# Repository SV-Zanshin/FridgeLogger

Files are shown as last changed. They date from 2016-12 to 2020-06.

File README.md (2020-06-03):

 Wiki (https://github.com/Zanduino/FridgeLogger/wiki)

 # FridgeLogger Program
*Arduino* sketch to log temperature and current consumption data to a microSD card. The statistics collected by this sketch are used to compute various parameters for a refrigerator or freezer. 

## Hardware
Rather than use a prebuilt Arduino, I used an Atmel ATMega 328PU chip with the Arduino bootloader and wired it up on a breadboard with a couple of hardware components, most of which aren't really necessary to the board's function.  I was curious about the Adafruit INA219 breakout board and wired that to the high-side power supply, then ran the power supply through an Adafruit Boost 500 to regulate the power supply, since I'm using rechargeable NiMh batteries and want to keep a nice constant 5V to the breadboard.  A Sparkfun DS1307 breakout board supplies the date and time for the log file. Rather than use a FTDI chip or JTAG programming, I wired in a (removable) Adafruit Bluefruit EZ-Link bluetooth wireless device which allows me to monitor the reading remotely as well as to program the board.
Logging is done using an Adafruit SD-Card breakout board.

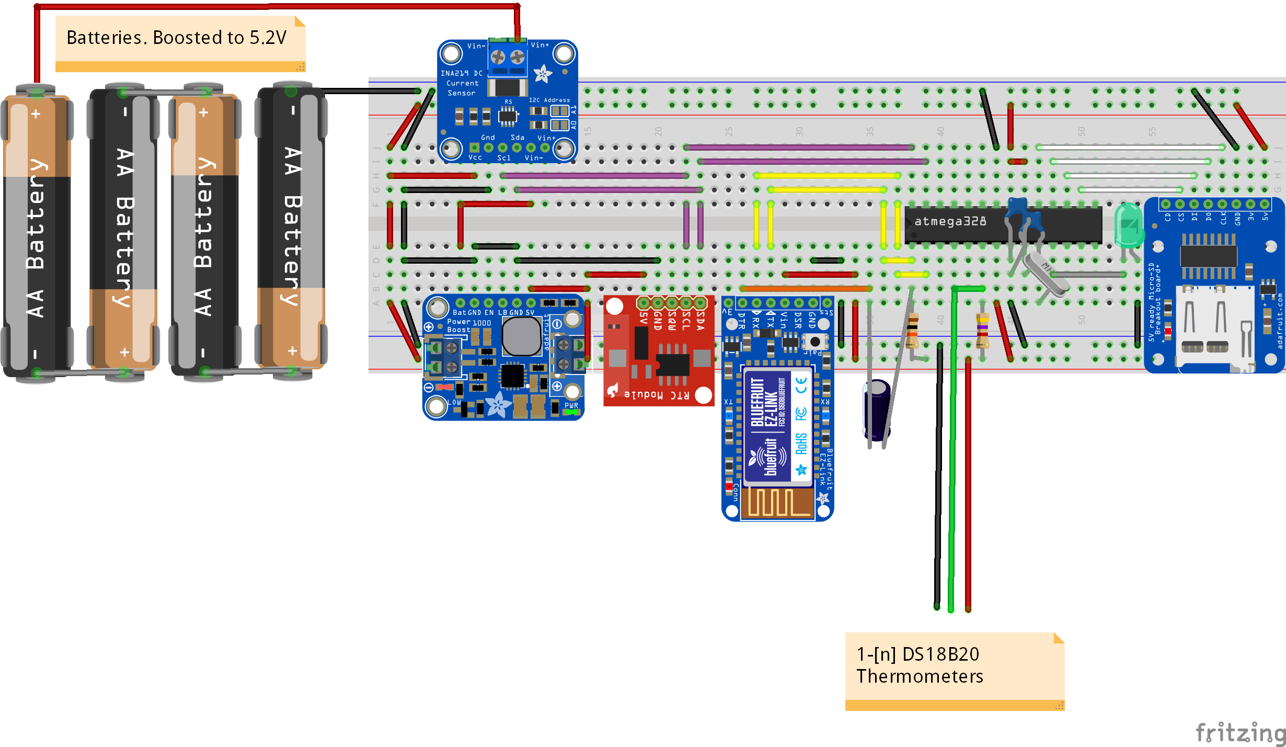
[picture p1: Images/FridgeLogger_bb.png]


## Software
The standard Arduino libraries are used as well as the specific ones for the Sparkfun/Adafruit breakout boards. In addition to these libraries the project makes use of the [DS-Family library](https://github.com/SV-Zanshin/DSFamily) to simplify managing numerous DS-Family type thermometers

## Output Files
The output is written to files on the SD-Card, with a new file started each day. The filename format is "GFYYMMDD.CSV" and the format is a DOS comma-separated variable file. The temperature readings in the file aren't in degrees Celsius, but in the 12-bit internal format used by the DS-Family of devices. Multiply the temperature readings by 0.0625°C to get degrees Celsius.

Zanshin Logo

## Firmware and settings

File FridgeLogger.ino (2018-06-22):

/*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
                            **
** ======= ========== =================== ======================================================================= **
** 1.0.1   2016-12-28 Arnd@SV-Zanshin.Com Added error checking for DS1307 returned date/time                      **
** 1.0.0   2016-12-27 Arnd@SV-Zanshin.Com Implemented                                                             **
** 1.0.0b2 2016-12-25 Arnd@SV-Zanshin.Com Added SD-Card                                                           **
** 1.0.0b1 2016-12-25 Arnd@SV-Zanshin.Com Initial coding.                                                         **
**                                                                                                                **
*******************************************************************************************************************/
#include <Adafruit_INA219.h>                                                  // INA219 Volts and Amps data       //
#include <RTClib.h>                                                           // DS1307 Real-Time-Clock commands  //
#include <SD.h>                                                               // SD-Card input and output         //
#include <avr/sleep.h>                                                        // Sleep mode Library               //
#include <DSFamily.h>                                                         // DS Thermometers calls and methods//
/*******************************************************************************************************************
** Declare program Constants                                                                                      **
*******************************************************************************************************************/
const uint8_t  GREEN_LED_PIN         =      5;                                // Green LED (nonstandard location) //
const uint8_t  CS_PIN                =     10;                                // Chip-Select pin for SD-Card      //
const uint8_t  INA219_I2C_ADDRESS    =   0x40;                                // I2C address = 1000000 (A0+A1=GND)//
const uint8_t  SPRINTF_BUFFER_SIZE   =     64;                                // Bytes in sprintf buffer          //
const uint16_t MEASUREMENT_MILLIS    =   5000;                                // Interval to perform measurements //
const uint16_t TIMER1_265DIV_10HZ    =  59286;                                // 65536 - (16Mhz/256/10)           //
const uint32_t SERIAL_SPEED          = 115200;                                // Use fast serial speed            //
const uint8_t  ONE_WIRE_PIN          =      4;                                // Digital Pin 2 for 1-Wire MicroLAN//
const char     FILE_PREFIX[3]        =   "GF";                                // Define output file prefix        //
/*******************************************************************************************************************
** Declare global variables and instantiate classes                                                               **
*******************************************************************************************************************/
Adafruit_INA219   INA219;                                                     // INA219 class instantiation       //
DSFamily_Class    DSFamily(ONE_WIRE_PIN);                                     // Instantiate the DSFamily class   //
RTC_DS1307        rtc;                                                        // Real-time-clock instantiation    //
char              sprintfBuffer[SPRINTF_BUFFER_SIZE];                         // Define buffer for sprintf        //
DateTime          now;                                                        // Define class to hold date & time //
File              dataFile;                                                   // Instantiate the SD file class    //
volatile uint16_t INA219_Readings   = 0;                                      // Number of INA219 readings done   //
volatile float    INA219_ShuntV     = 0;                                      // Sum for averaging Shunt Voltage  //
volatile float    INA219_BusV       = 0;                                      // Sum for averaging Bus Voltage    //
volatile float    INA219_mA         = 0;                                      // Sum for averaging MilliAmperes   //
uint16_t          ThermometersFound = 0;                                      // Store device detected count      //
uint8_t           Today             = UINT8_MAX;                              // Current day-of-week              //
/*******************************************************************************************************************
** Declare prototypes for all functions used                                                                      **
*******************************************************************************************************************/
void    setup();                                                              // Called once on power-up/restart  //
void    loop();                                                               // Called repeatedly after setup()  //
void    sleep(const uint16_t SleepMilliseconds);                              // Save on power consumption        //
void    openFile();                                                           // Open SD-Card file, if necessary  //
/*******************************************************************************************************************
** This is the function which collects the INA219 voltage and amperage statistics, it is triggered by an overflow **
** interrupt on TIMER1 which is set to about 10Hz (10 times a second) using the value of TIMER1_265DIV_10HZ. Once **
** triggered, it re-enables interrupts, which are turned off by default inside interrupt vectors, and calls the   **
** INA219 library commands to retrieve the voltage and current information and add them to the global variables.  **
*******************************************************************************************************************/
ISR(TIMER1_OVF_vect) {                                                        // Timer1 overflow service routine  //
  sei();                                                                      // Enable interrupts for INA219     //
  INA219_ShuntV += INA219.getShuntVoltage_mV();                               // Add reading to sum               //
  INA219_BusV   += INA219.getBusVoltage_V();                                  // Add reading to sum               //
  INA219_mA     += INA219.getCurrent_mA();                                    // Add reading to sum               //
  cli();                                                                      // Disable interrupts again         //
  INA219_Readings++;                                                          // Increment readings counter       //
  TCNT1 = TIMER1_265DIV_10HZ;                                                 // Set timer again                  //
} // of method timer1 overflow vector                                         //                                  //
/*******************************************************************************************************************
** Method sleep() will put the system into a low-energy mode for the given number of milliseconds. Any wake-ups   **
** such as interrupt that occur during this sleep period are handled and then the system goes back to sleep.      **
*******************************************************************************************************************/
void sleep(const uint16_t SleepMilliseconds) {                                //                                  //
  uint32_t SleepUntil = millis() + SleepMilliseconds;                         // Set time we want to sleep until  //
  bool     LEDState   = digitalRead(GREEN_LED_PIN);                           // Store value of pin               //
  digitalWrite(GREEN_LED_PIN,false);                                          // Turn off LED while we sleep      //
  ADCSRA = 0;                                                                 // turn off the ADC module          //
  while(millis()<=SleepUntil) {                                               // Put the system into sleep mode   //
    set_sleep_mode(SLEEP_MODE_IDLE);                                          // Set the minimum power savings    //
    cli();                                                                    // disable interrupts               //
    sleep_enable();                                                           // Enable sleep, but don't sleep yet//
    sei();                                                                    // Re-enable interrupts             //
    sleep_cpu ();                                                             // Sleep within 3 clock cycles      //
  } // of while we don't have anything to do                                  // of re-enabling interrupts        //
  digitalWrite(GREEN_LED_PIN,LEDState);                                       // Restore LED state                //
  ADCSRA = B10000000;                                                         // turn the ADC module back on      //
  digitalWrite(GREEN_LED_PIN,HIGH);                                           // Turning on LED                   //
} // of method sleep()                                                        //                                  //
/*******************************************************************************************************************
** Method openFile() will open up a file with today's date for writing on the SD-Card. the filename is named as   **
** "GF{yy}{mm}{dd}.CSV" and it is a comma-separated file for use in Excel.                                        **
*******************************************************************************************************************/
void openFile() {                                                             //                                  //
  if ( now.day() != Today || !dataFile) {                                     // If the day has changed           //
    if (dataFile) dataFile.close();                                           // close the file, if it was open   //
    Today = now.day();                                                        // store current day of the month   //
    sprintf(sprintfBuffer,"%s%02d%02d%02d.CSV", FILE_PREFIX,                  // Format an 8.3 type filename      //
            now.year()-2000,now.month(),now.day());                           //                                  //
    dataFile = SD.open(sprintfBuffer, FILE_WRITE);                            // creates file if it doesn't exist //
    if (dataFile) {                                                           // If file was successfully opened  //
      if (dataFile.position()==0) {                                           // Then if the file was empty, add  //
        dataFile.print(F("Date,Time,Input Volts,milliAmps"));                 // the header line                  //
        for(uint8_t i=0;i<DSFamily.ThermometersFound;i++) {                   // Add each thermometer found to    //
          sprintf(sprintfBuffer,",Temp%02d",i);                               // the output                       //
          dataFile.print(sprintfBuffer);                                      //                                  //
        } // of loop for each thermometer found                               //                                  //
        dataFile.println();                                                   // Terminate line                   //
      } // of if-then we have an empty file                                   //                                  //
    } else {                                                                  //                                  //
      Serial.print(F("Error opening \""));                                    //                                  //
      Serial.print(sprintfBuffer);                                            //                                  //
      Serial.print(F("\"\n"));                                                //                                  //
    } // if-then-else file could be opened                                    //                                  //
  } // we have a new day and need to open a new file                          //                                  //
} // of method openFile()                                                     //                                  //
/*******************************************************************************************************************
** Method Setup(). This is an Arduino IDE method which is called first upon initial boot or restart. It is only   **
** called one time and all of the variables and other initialization calls are done here prior to entering the    **
** main loop for data measurement and storage.                                                                    **
*******************************************************************************************************************/
void setup() {                                                                //                                  //
  pinMode(GREEN_LED_PIN, OUTPUT);                                             // Define the green LED as an output//
  pinMode(CS_PIN,OUTPUT);                                                     // Declare CS_PIN as an output pin  //
  Serial.begin(SERIAL_SPEED);                                                 // Start serial communications      //
  ThermometersFound = DSFamily.ScanForDevices();                              // Search for thermometers on 1-Wire//
  Serial.print(F("\n\nFridgeLogger V1.0.1b\n"));                              // Display program information      //
  INA219.begin(INA219_I2C_ADDRESS);                                           // Start the INA219 breakout        //
  INA219.setCalibration_16V_400mA();                                          // Lowest voltage / highest accuracy//
  rtc.begin();                                                                // Start the RTC interface          //
  if ( !rtc.isrunning()) rtc.adjust(DateTime(F(__DATE__), F(__TIME__)));      // Set clock to compile date/time   //
  now = rtc.now();                                                            // Get the Date and Time from DS1307//
  Today = now.day();                                                          // Store the current day of month   //
  sprintf(sprintfBuffer,"Now: %04d-%02d-%02d %02d:%02d:%02d\n",now.year(),    // Put together the display string  //
          now.month(), now.day(),now.hour(),now.minute(),now.second());       //                                  //
  Serial.print(sprintfBuffer);                                                // Output the display string        //
  if (ThermometersFound==0)                                                   // If we have searched but not found//
    Serial.println(F("No thermometers detected!"));                           // show the error message           //
  else {                                                                      // or                               //
    Serial.print(F("Found "));                                                // Display devices found            //
    Serial.print(ThermometersFound);                                          //                                  //
    Serial.print(F(" devices.\n"));                                           //                                  //
  } // of if-then-else no devices found                                       //                                  //
  Sd2Card card;                                                               // Instantiate Micro-SD Card class  //
  if (!card.init(SPI_HALF_SPEED,CS_PIN))                                      // Initialize the card              //
    Serial.print(F("- SD Initialization failed. Insert card, restart.\n"));   // Show error message               //
  SdVolume volume;                                                            // Instantiate Micro-SD Volume      //
  if (!volume.init(card))                                                     // Check to find partition          //
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
void loop() {                                                                 // Main program loop                //
  static bool FirstLoop = true;                                               // Initialized for 1st iteration    //
  sleep(MEASUREMENT_MILLIS);                                                  // Low-Energy until wake-up time    //
  openFile();                                                                 // Open output file, if necessary   //
  if (FirstLoop) {                                                            // If first time the display header //
    Serial.print(F("## BusVolts Shunt mV Current mA milliWatts\n"));          //                                  //
    Serial.print(F("== ======== ======== ========== ==========\n"));          //                                  //
    FirstLoop = false;                                                        // Reset flag after showing header  //
  } // of if-then we need to display header                                   //                                  //
  Serial.print(INA219_Readings);                                              //                                  //
  Serial.print(F("     "));                                                   //                                  //
  Serial.print(INA219_BusV/INA219_Readings,2);                                //                                  //
  Serial.print(F("     "));                                                   //                                  //
  Serial.print(INA219_ShuntV/INA219_Readings,2);                              //                                  //
  Serial.print(F("      "));                                                  //                                  //
  Serial.print(INA219_mA/INA219_Readings,2);                                  //                                  //
  Serial.print(F("     "));                                                   //                                  //
  Serial.println((INA219_BusV/INA219_Readings)*(INA219_mA/INA219_Readings),2);//                                  //
  now = rtc.now();                                                            // Get the Date and Time from DS1307//
  while (now.year()>(uint16_t)2100) now = rtc.now;                            // RTC returns bad value sometimes  //
  cli();                                                                      // disable interrupts               //
  sprintf(sprintfBuffer,"%04d-%02d-%02d,%02d:%02d:%02d,%d.%02d,%d.%02d",      // Build up the output line using   //
        now.year(),now.month(),now.day(),                                     // formatting and avoiding floating //
        now.hour(),now.minute(),now.second(),                                 // point output, as sprintf() on the//
        (int)(INA219_BusV/INA219_Readings),                                   // Arduino doesn't support it.      //
        (int)(INA219_BusV/INA219_Readings*100)%100,                           //                                  //
        (int)(INA219_mA/INA219_Readings),                                     //                                  //
        (int)(INA219_mA/INA219_Readings*100)%100 );                           //                                  //
  INA219_ShuntV   = 0;                                                        // Reset values after processing    //
  INA219_BusV     = 0;                                                        //                                  //
  INA219_mA       = 0;                                                        //                                  //
  INA219_Readings = 0;                                                        //                                  //
  sei();                                                                      // Re-enable interrupts             //
  dataFile.print(sprintfBuffer);                                              // Write to SD-Card                 //
  Serial.print(sprintfBuffer);                                                // Display to serial port           //
  for(uint8_t i=0;i<DSFamily.ThermometersFound;i++) {                         // Loop for each thermometer  found //
    Serial.print(F(","));                                                     // display to serial port           //
    dataFile.print(F(","));                                                   // format output line               //
    int16_t temperature = DSFamily.ReadDeviceTemp(i);                         // Read the raw temperature value   //
    Serial.print(temperature);                                                // write output                     //
    dataFile.print(temperature);                                              // write output                     //
  } // for-next every thermometer loop                                        //                                  //
  DSFamily.DeviceStartConvert();                                              // Start conversion on all devices  //
  dataFile.println();                                                         // Write to SD-Card                 //
  dataFile.flush();                                                           // force write everything in memory //
  Serial.println();                                                           // Display to serial port           //
} // of method loop                                                           //----------------------------------//

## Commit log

2016-12-27 Initial Creation
    Initial project upload
    [GosFridge.fzz]
2016-12-29 Added error checking to RTC
    The RTC occasionally returns invalid dates, this is now sanity-checked
    and corrected.
    [FridgeLogger.ino]
2018-06-26 Removed Arduino as linguist language

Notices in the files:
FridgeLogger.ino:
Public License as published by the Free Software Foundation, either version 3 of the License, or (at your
